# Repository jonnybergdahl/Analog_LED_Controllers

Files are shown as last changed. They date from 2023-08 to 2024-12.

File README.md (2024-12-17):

# Analog_LED_Controller

This repository contains 2 versions of a two channel analog LED controller. 

> Note: This is only suitable for LED lights powered by a fixed voltage, such as plant lights and LED strips. It does not work with raw LED's that need a constant current/voltage driver. 

One version is for 5V USB connected lights, the "USB version", and the other version is for 5-24V lights, the "Power jack version" using standard 5.5/2.1 mm power jacks. They are based on an ESP32-PICO-MINI-2 module, and I use it with ESPHome firmware to publish the lights to Home Assistant. Inside of Home Assistant you can dim the lights and turn them on or off. Both have a power jack input for power, make sure to use a power supply with center positive.

> Note: The boards have reverse power input protection for the internal circuitry only. The LED's outputs are protected by resettable fuses. This should not pose any problems as long as you only power LED's, since they are themselves diodes and thus already protected from reverse power.

The input power jack is rated for maximum 5A so depending on input voltage the max combined power is:
 - 5V: 25W
 - 12V: 60W
 - 24V: 120W

### USB version
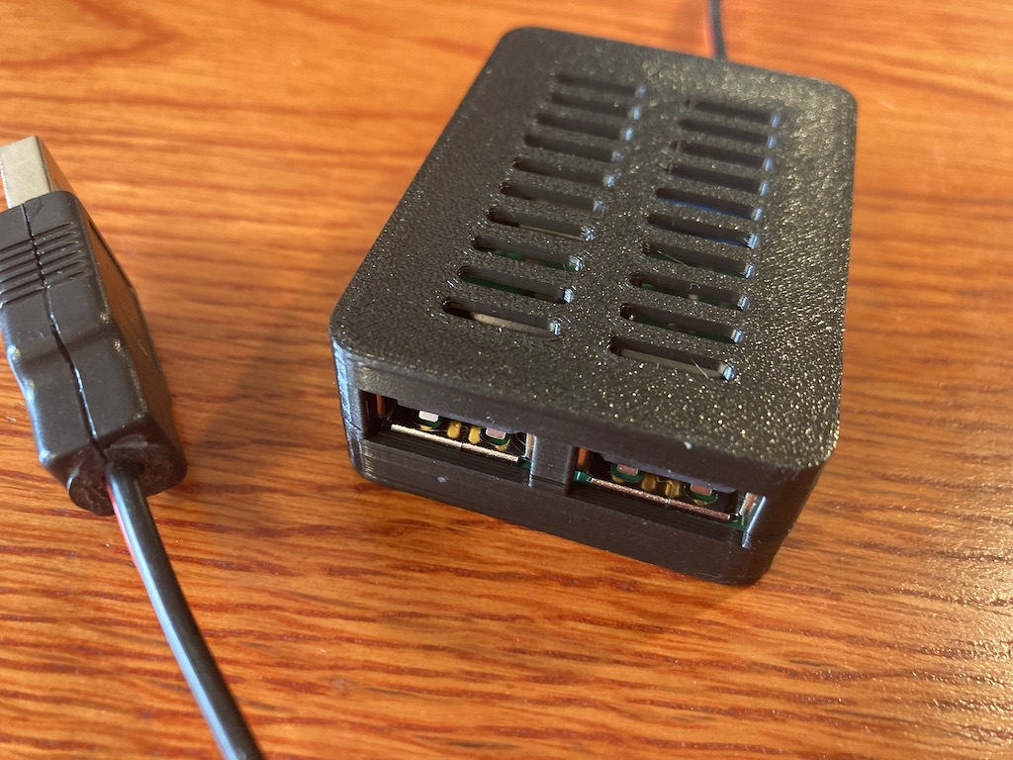
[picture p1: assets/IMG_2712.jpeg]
USB version


### Power jack version
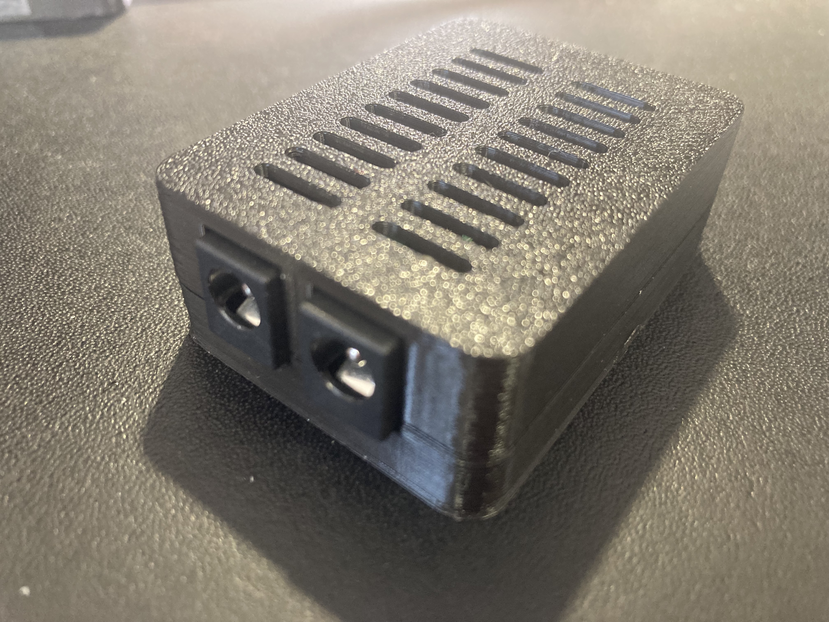
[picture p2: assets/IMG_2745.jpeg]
Power jack version


The gerber files for PCB manufacturing are located in the [gerber folder](gerber/).

I highly recommend you order a stencil together with the PCB, as the ESP32 module only exposes tiny pads on the bottom of the module and it is hard to get the correct amount of solder paste without one.

PCB design files are available in [EAGLE format](pcb/).

The Schematic is also available in PDF Format, [USB version](https://github.com/jonnybergdahl/Project_Analog_LED_Controllers/blob/main/pcb/5V_Analog_Controller.pdf) and [Power jack version](https://github.com/jonnybergdahl/Project_Analog_LED_Controllers/blob/main/pcb/12V_Analog_Controller.pdf).

## Parts needed

BOM file are located here: 
 - [USB version](pcb/USB_Analog_Controller.csv)
 - [Power jack version](pcb/USB_Analog_Controller%2024V.csv).

> Note: There is space for 2 PTC's per channel in case you need more current than a single PTC can handle. Make sure to use PTC's rated for the voltage _and_ current you want. The JK-SMD300L-24 in the BOM are rated for max 24V and a hold current of 3 ampere.

### USB version
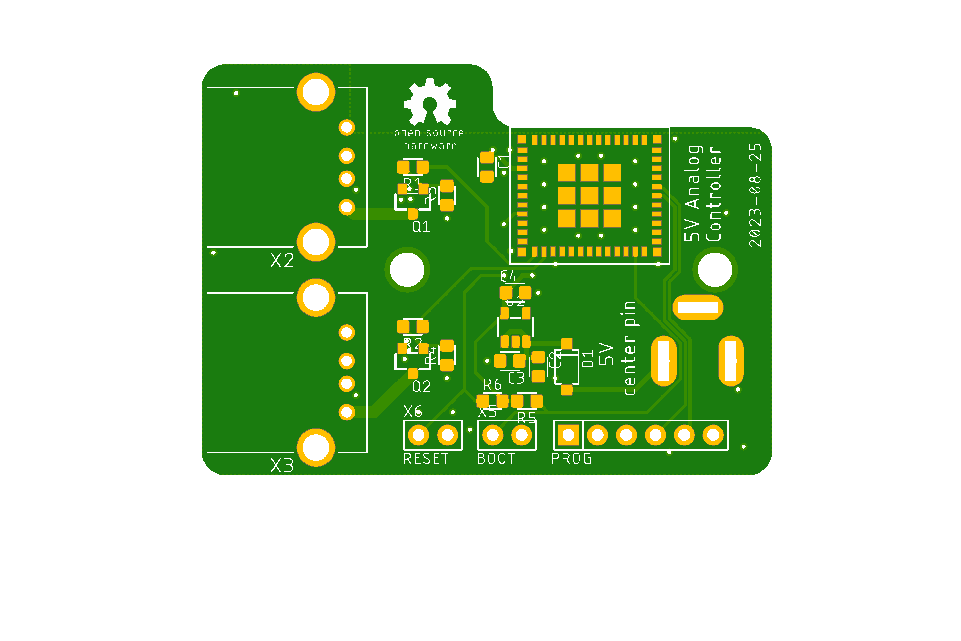
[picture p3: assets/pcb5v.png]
USB version PCB


### Power jack version
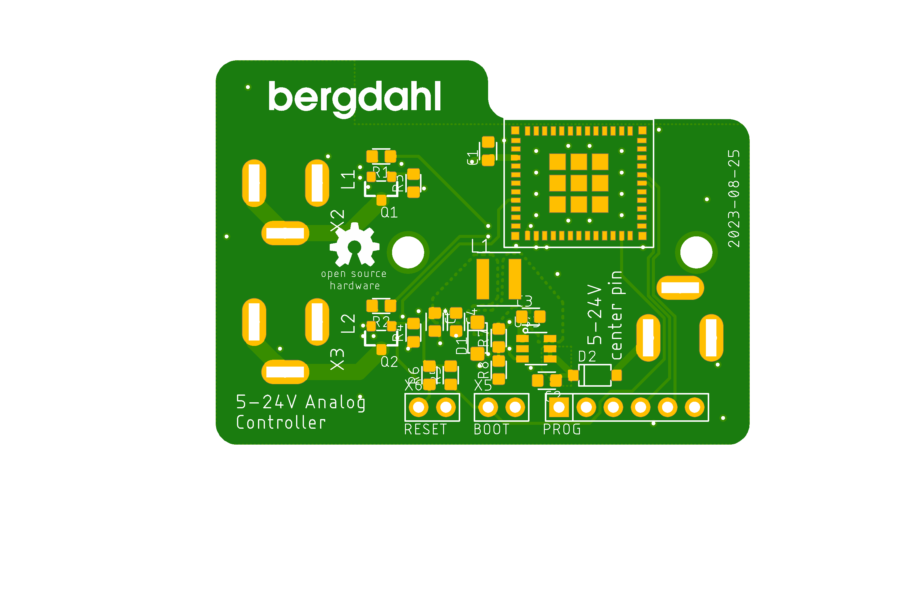
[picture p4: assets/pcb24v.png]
Power Jack version PCB


See the [BOM file](pcb/LED_USB_Analog_Controller.csv) for the component list.

## Enclosure

The enclosure files are located in the [enclosure folder](enclosure/). There are two `3mf` files for 3D printing for each device, and I also added the original _Fusion 360_ design files in case you need to make modifications.

## Assembly

 Start by soldering all SMD parts onto the PCB. I used a hot plate for resoldering, but a hot air soldering station will also work. Continue by using a soldering iron to solder the connectors. For the USB version, Cut an existing USB cable or do like me and solder up your own, and screw plus and minus to the screw terminals (Depending on the power usage of the lights, you may need thicker cables than normal USB cables, that is why I make my own power only ones). 

The enclosure is press fit so does not need any extra hardware or tools.

## Programming

Create a new device in _ESPHome_ and replace the `yaml` with the contents of [the yaml code here](firmware/led1.yaml). Change `name` and `friendly_name` as needed.

The actual programming is done by using a standard FT232 serial board connected to the programming header. If you don't own a FT232 adapter, you can use other types of serial adapters by hooking up `GND`, `TX` and `RX` like this.

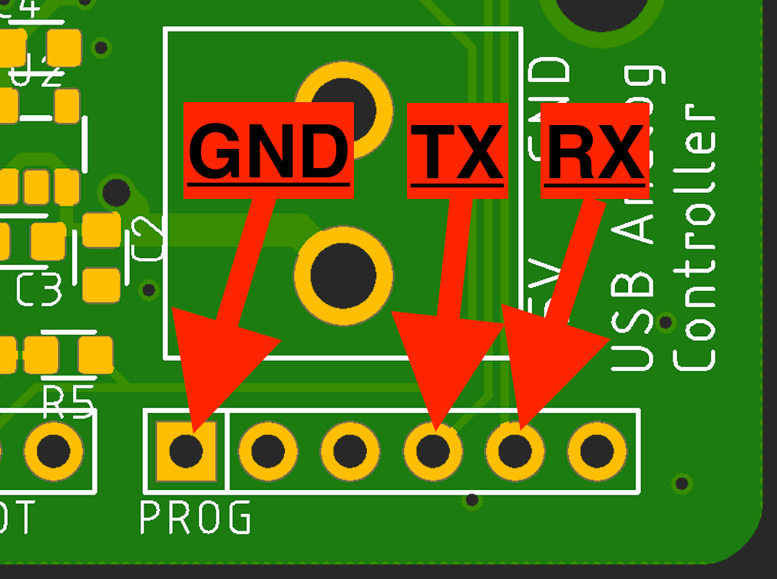
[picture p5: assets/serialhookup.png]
Serial connection


Insert the programmer and short the `BOOT` header. It can be done by soldering a temporary lead between the pads (I just insert tweezers into the pads). Apply power and it is ready for programming.

In _EspHome_,  click `Install` - `Manual download` - `Modern format`. _EspHome_ will compile the code and after couple of minutes the firmware file will be downloaded. 

Open the [ESPHome programming page](https://web.esphome.io/) and click `CONNECT`. Select the FT232 serial port and click `Connect`. Select `Install` and then click `Select file`. Select the file downloaded in the previous step and then click `Install`. The install will now proceed.

When install is finished, just remove the FT232 board and `BOOT` jumper, disconnect and connect power, and after a while Home Assistant will autodetect it. Just add the device as usual and you will get a device with the following entities in Home Assistant. 

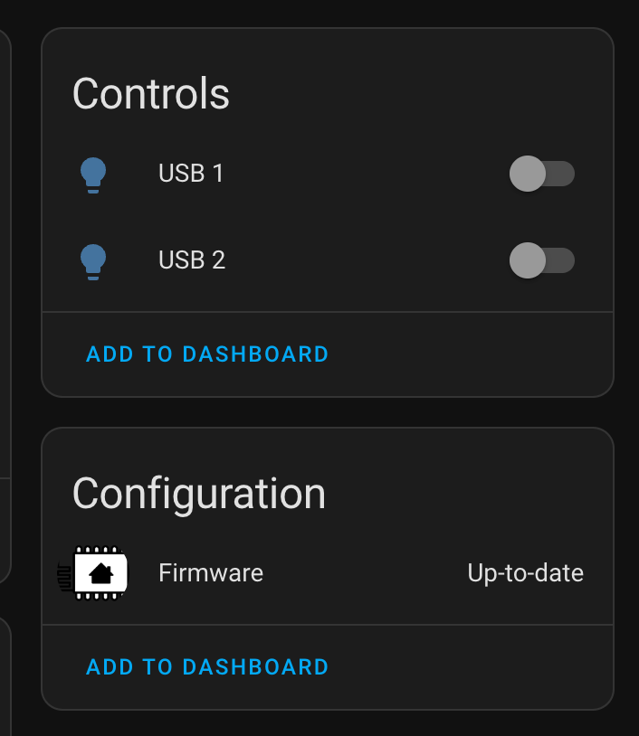
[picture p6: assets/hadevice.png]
Home Assistant view


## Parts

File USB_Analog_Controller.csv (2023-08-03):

Qty | Value | Device | Package | Parts | Description
2 | 100R | RESISTOR0603 | R0603 | R1, R2
1 | 100nF | CAPC0603 | C0603 | C1
4 | 10K | RESISTOR0603 | R0603 | R3, R4, R5, R6
3 | 1uF | CAPC0603 | C0603 | C2, C3, C4
2 | 3A | PTCJK-SMD300 | JK-SMD300 | F1, F2
2 | AO3400 | MOSFET-NCHSOT23-3 | SOT23-3 | Q1, Q2
1 | AP2112K | REGULATOR-AP2112KK-SOT23-5 | SOT23-5 | U2
1 | BOOT | HEADER-1X02-2.54 | 1X02-2.54 | X5
1 | LED1 | USB-ASS-52100-001 | USB-A-SS-52100-001 | X2
1 | LED2 | USB-ASS-52100-001 | USB-A-SS-52100-001 | X3
1 | PICO-MINI-02 | ESP32-PICO-MINI-02 | ESP32-PICO-MINI-02 | U1
1 | POWER | TERMINAL-1X02-5.08 | TERMINAL-5.08-2P | J1 | https://www.digikey.se/product-detail/sv/on-shore-technology-inc/OSTTC022162/ED2609-ND/614558
1 | PROG | HEADER-FTDI232 | FTDI232-1X06 | X1
1 | RESET | HEADER-1X02-2.54 | 1X02-2.54 | X6

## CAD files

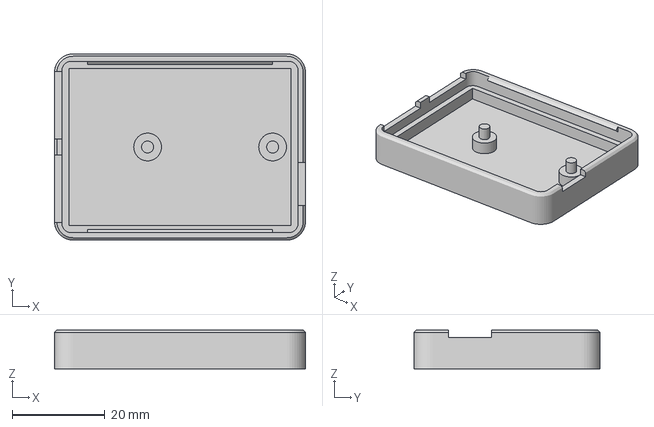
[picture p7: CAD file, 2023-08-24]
enclosure/5V Analog LED Controller Top.3mf
54.2 x 40.2 x 8.40 mm

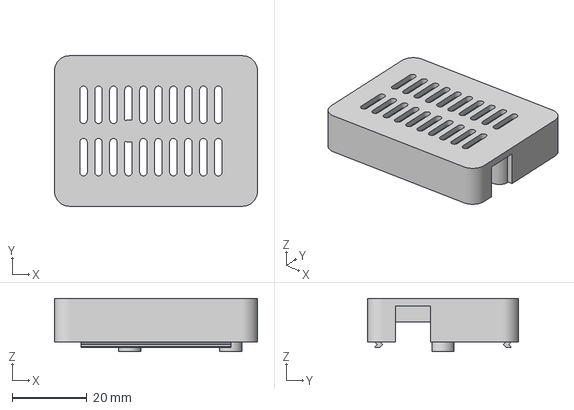
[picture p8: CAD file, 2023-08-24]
enclosure/5V Analog LED Controller Bottom.3mf
54.2 x 40.2 x 14.2 mm

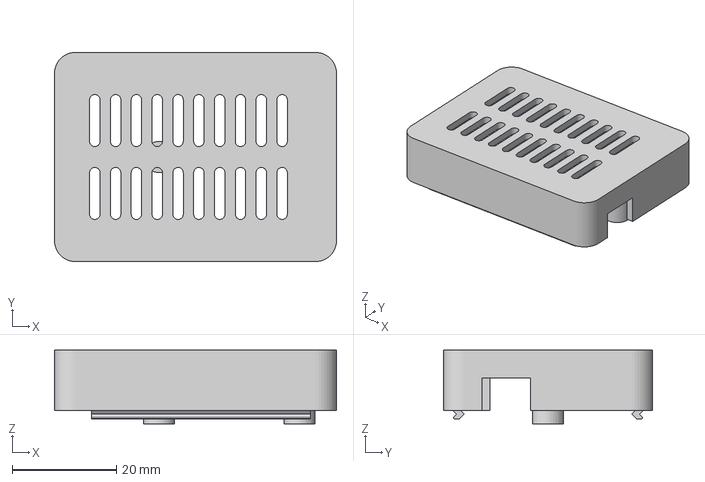
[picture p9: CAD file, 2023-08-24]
enclosure/12V Analog LED Controller Top.3mf
54.2 x 40.2 x 14.2 mm

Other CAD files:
enclosure/12V Analog LED Controller Bottom.3mf
enclosure/12V Analog LED Controller Enclosure.f3d
enclosure/5V Analog LED Controller Enclosure.f3d

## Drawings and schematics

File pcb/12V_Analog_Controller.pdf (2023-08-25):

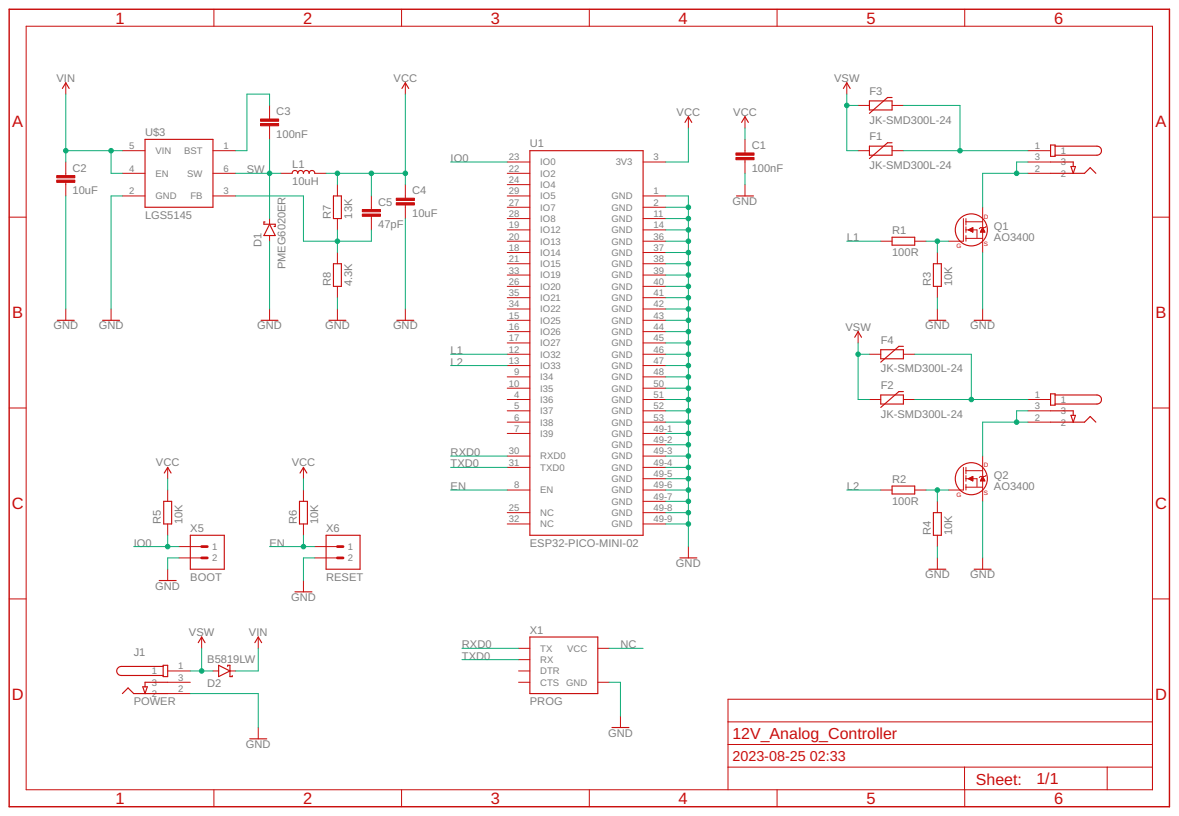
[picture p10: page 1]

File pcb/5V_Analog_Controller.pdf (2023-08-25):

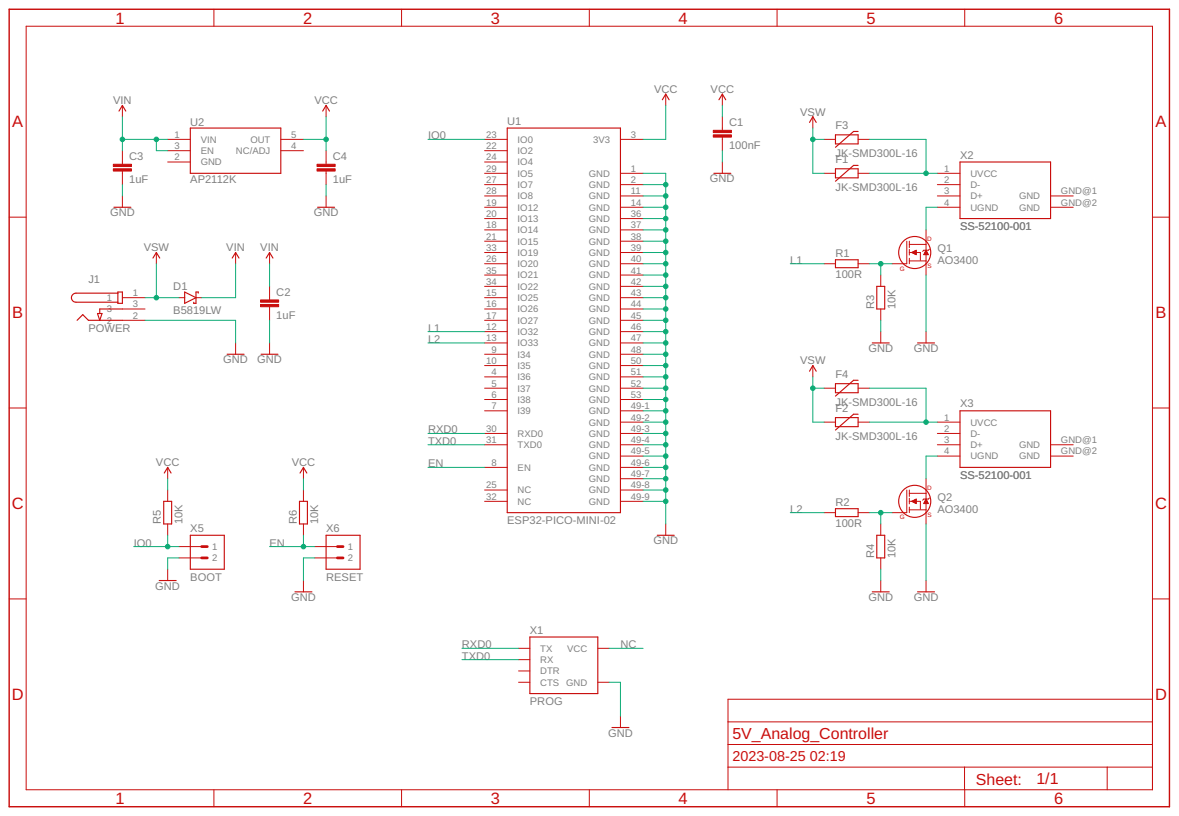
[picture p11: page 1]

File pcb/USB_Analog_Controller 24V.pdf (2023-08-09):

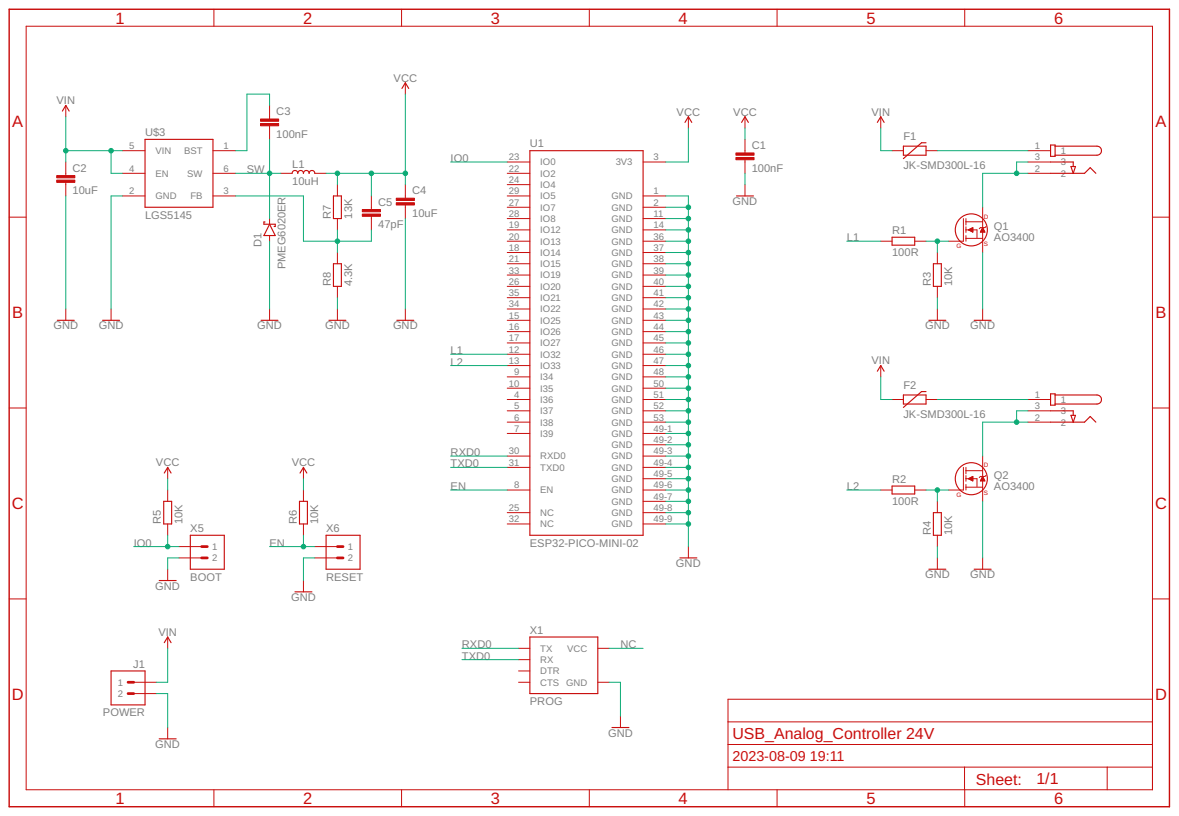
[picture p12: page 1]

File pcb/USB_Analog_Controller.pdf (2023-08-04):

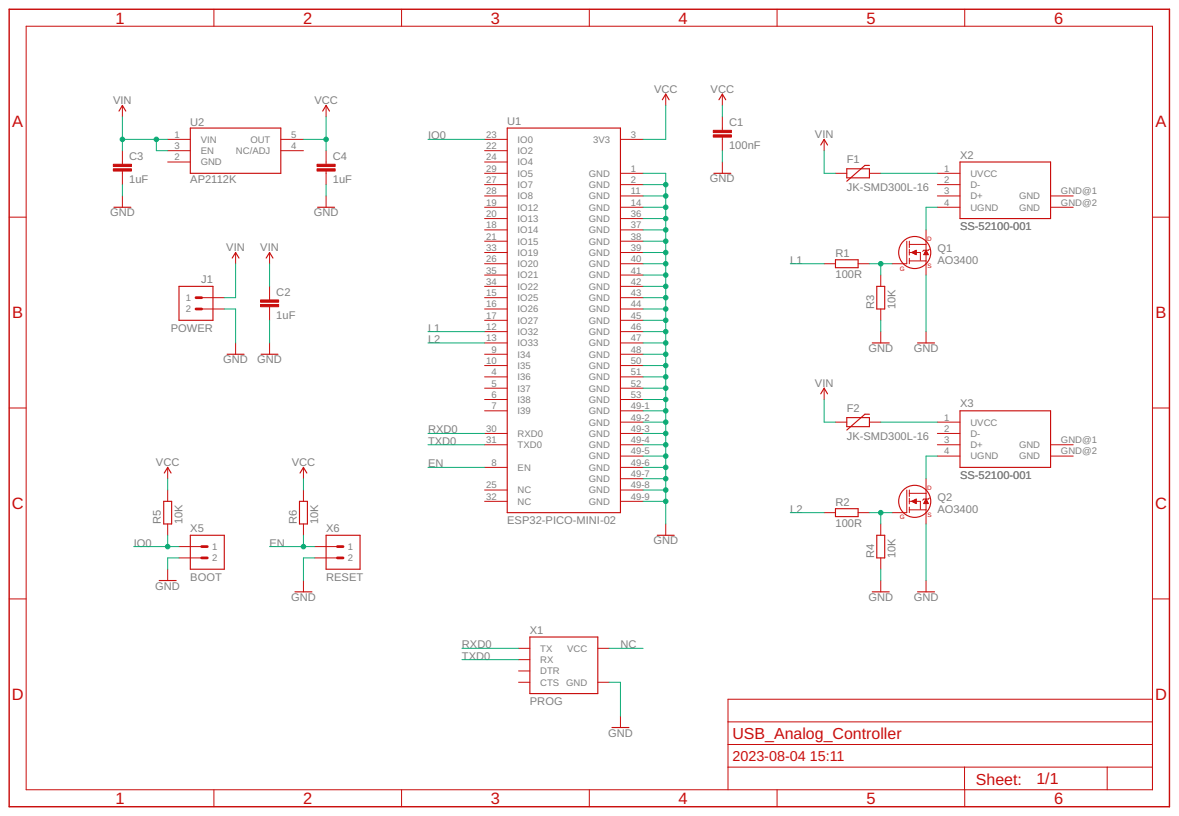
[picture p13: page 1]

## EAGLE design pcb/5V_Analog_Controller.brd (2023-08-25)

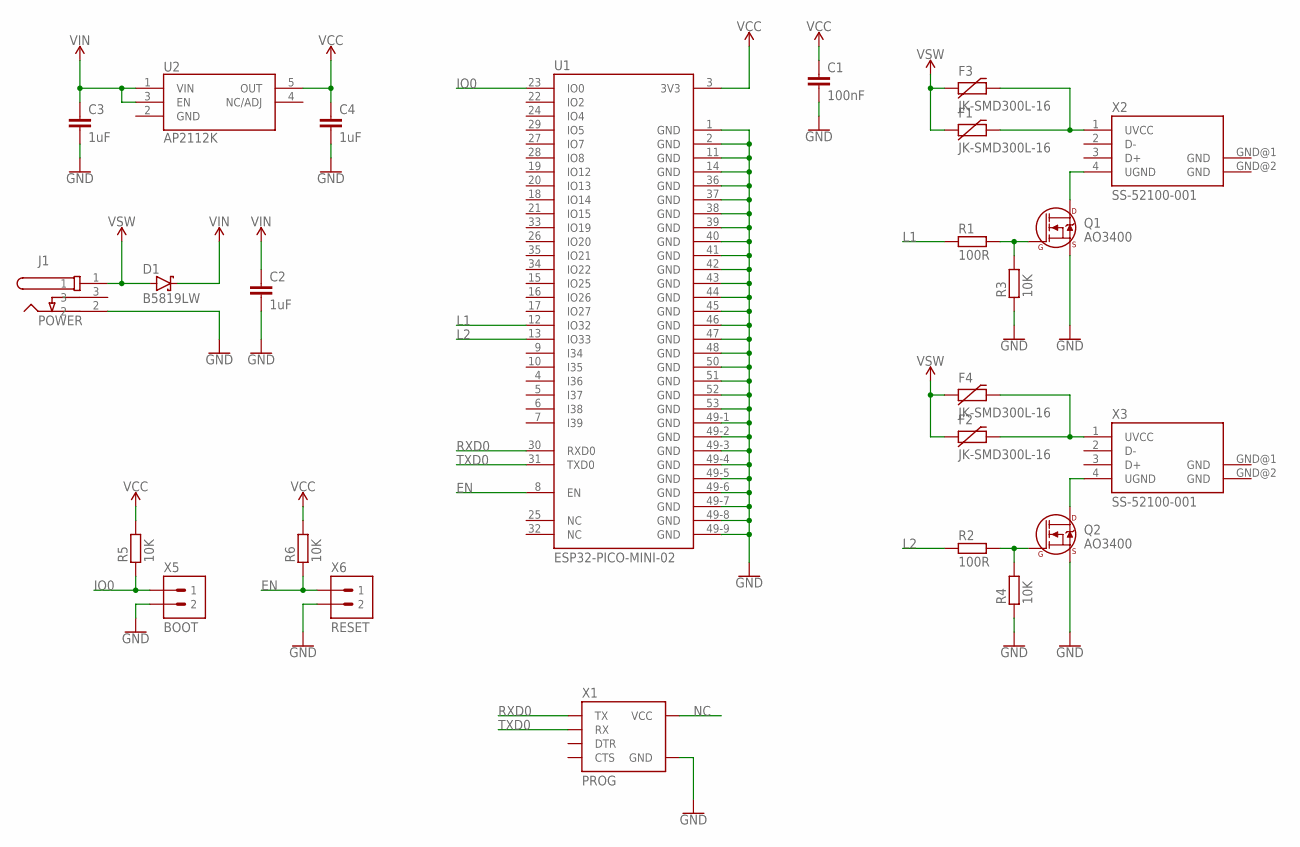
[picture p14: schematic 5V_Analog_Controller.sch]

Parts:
C1: 100nF; C0603
C2, C3, C4: 1uF; C0603
D1: B5819LW; SOD-123
F1, F2, F3, F4: JK-SMD300L-16; JK-SMD300
J1: POWER; XKB-DC-005-5A-2.0
Q1, Q2: AO3400; SOT23-3
R1, R2: 100R; R0603
R3, R4, R5, R6: 10K; R0603
U1: ESP32-PICO-MINI-02
U2: AP2112K; SOT23-5
X1: PROG; FTDI232-1X06
X2, X3: SS-52100-001; USB-A-SS-52100-001
X5: BOOT; 1X02-2.54
X6: RESET; 1X02-2.54

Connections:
EN: R6.1, U1.8 (EN), X6.1
GND: C1.2, C2.2, C3.2, C4.2, J1.2, Q1.2 (S), Q2.2 (S), R3.1, R4.1, U1.1 (GND), U1.2 (GND), U1.11 (GND), U1.14 (GND), U1.36 (GND), U1.37 (GND), U1.38 (GND), U1.39 (GND), U1.40 (GND), U1.41 (GND), U1.42 (GND), U1.43 (GND), U1.44 (GND), U1.45 (GND), U1.46 (GND), U1.47 (GND), U1.48 (GND), U1.49-1 (GND), U1.49-2 (GND), U1.49-3 (GND), U1.49-4 (GND), U1.49-5 (GND), U1.49-6 (GND), U1.49-7 (GND), U1.49-8 (GND), U1.49-9 (GND), U1.50 (GND), U1.51 (GND), U1.52 (GND), U1.53 (GND), U2.2 (GND), X1.GND, X5.2, X6.2
IO0: R5.1, U1.23 (IO0), X5.1
L1: R1.1, U1.12 (IO32)
L2: R2.1, U1.13 (IO33)
unnamed: Q1.3 (D), X2.4 (UGND)
unnamed: Q2.3 (D), X3.4 (UGND)
unnamed: Q2.1 (G), R2.2, R4.2
unnamed: Q1.1 (G), R1.2, R3.2
unnamed: F1.B (2), F3.B (2), X2.1 (UVCC)
unnamed: F2.B (2), F4.B (2), X3.1 (UVCC)
NC: X1.VCC
RXD0: U1.30 (RXD0), X1.TX
TXD0: U1.31 (TXD0), X1.RX
VCC: C1.1, C4.1, R5.2, R6.2, U1.3 (3V3), U2.5 (OUT)
VIN: C2.1, C3.1, D1.C, U2.1 (VIN), U2.3 (EN)
VSW: D1.A, F1.A (1), F2.A (1), F3.A (1), F4.A (1), J1.1

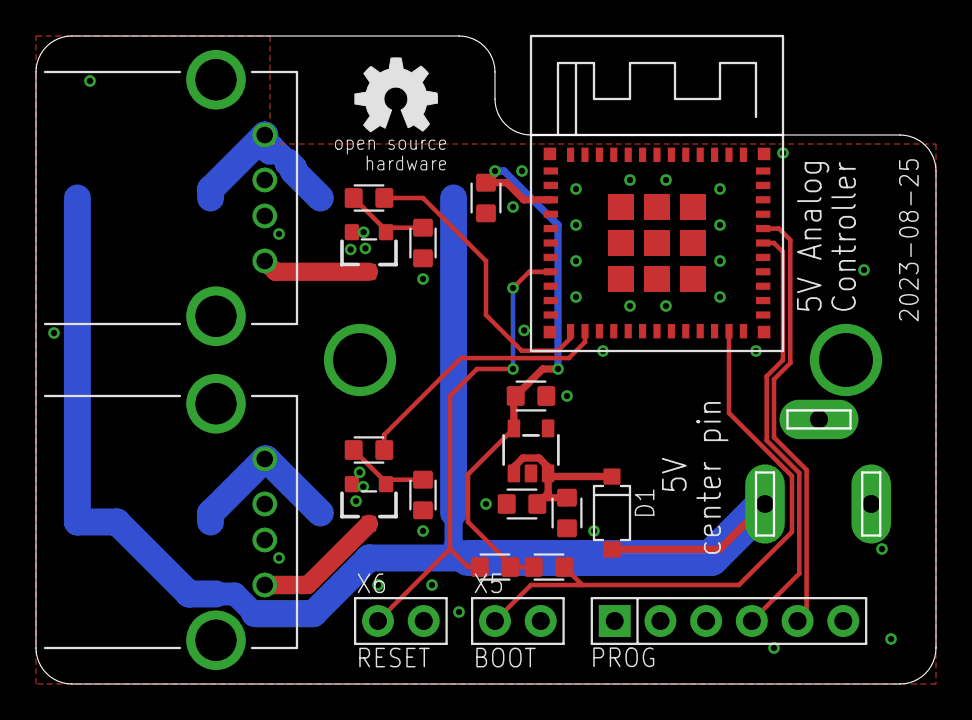
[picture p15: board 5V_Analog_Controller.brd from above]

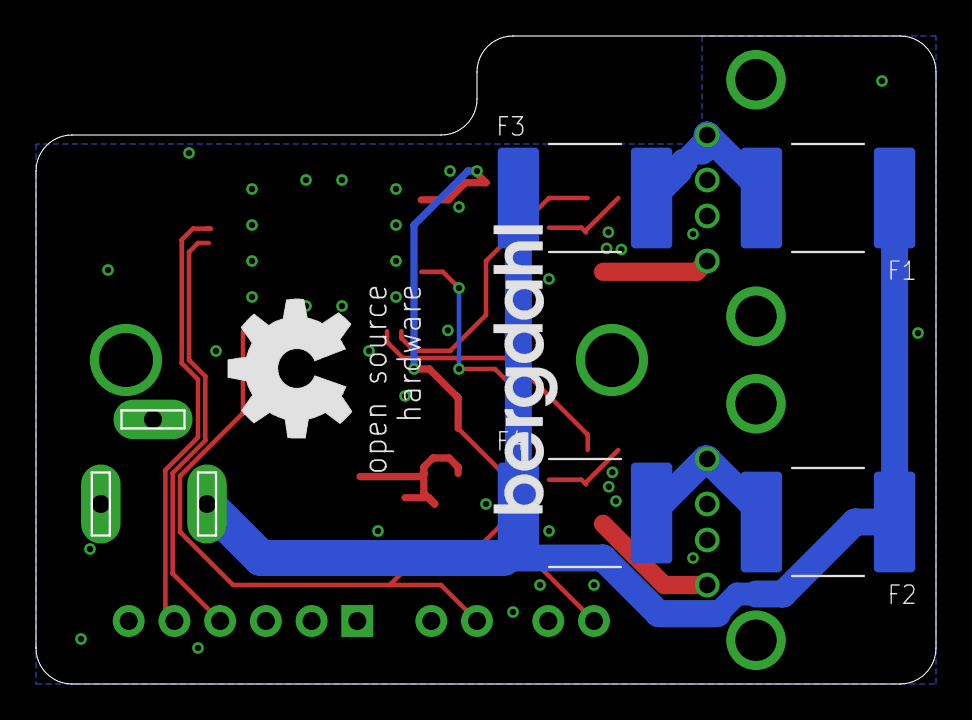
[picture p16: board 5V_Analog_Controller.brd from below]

Board: 2 copper layers, 50.0 x 36.0 mm, 28 parts (4 on the bottom side), 16 nets.

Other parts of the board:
U$1: BERGDAHL-20MM-BPLACE
U$2: OSHW-8MM-BPLACE
U$3: OSHW-5MM-TPLACE

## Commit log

2023-06-03 Initial version
    [LED_USB_Analog_Controller.brd, LED_USB_Analog_Controller.sch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]
2023-07-17 Revision 2023-07-17
    [LED_USB_Analog_Controller.csv, USB_Analog_Controller.brd, USB_Analog_Controller.sch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]
2023-07-27 Added PTC fuse
    [USB_Analog_Controller.brd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]
2023-08-03 Final PCB version
    [LED USB Analog Controller Enclosure.f3d, LED_USB_Analog_Controller.brd, LED_USB_Analog_Controller_Bottom.3mf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]
2023-08-04 Revision 2023-08-04 Switch power connector Add PDF file Cleanup old PCB files
    [LED_USB_Analog_Controller.brd, LED_USB_Analog_Controller.csv, LED_USB_Analog_Controller.sch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]
2023-08-09 Add 5-24V version
    [USB_Analog_Controller 24V.GBL, USB_Analog_Controller 24V.GBO, USB_Analog_Controller 24V.GBP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]
2023-08-09 Add missing drill file
2023-08-14 Change connector on24V PCB Cosmetic fixes on 24V PCB
    [USB_Analog_Controller 24V.brd, USB_Analog_Controller 24V.csv, USB_Analog_Controller 24V.sch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]
2023-08-20 Major renaming work
    [12V Analog LED Controller Bottom.3mf, 12V Analog LED Controller Enclosure.f3d, 12V Analog LED Controller Top.3mf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]
2023-08-20 Moved repo to better named location
    [12V_Analog_Controller.GBL, 12V_Analog_Controller.GBO, 12V_Analog_Controller.GBP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]
2023-08-20 Revert "Major renaming work"
    This reverts commit 9d1dc4bb5ff05094a4a5c98072b5adfe142c2125.
    [12V Analog LED Controller Bottom.3mf, 12V Analog LED Controller Enclosure.f3d, 12V Analog LED Controller Top.3mf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]
2023-08-20 Moved all files
    [12V Analog LED Controller Bottom.3mf, 12V Analog LED Controller Enclosure.f3d, 12V Analog LED Controller Top.3mf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]
2023-08-20 Fix snap issue
    [12V Analog LED Controller Bottom.3mf, 12V Analog LED Controller Enclosure.f3d, 12V Analog LED Controller Top.3mf]
2023-08-24 Switch to input power jack
    [12V_Analog_Controller.brd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]
2023-08-24 Add reverse power protection for internal circuits
    [12V_Analog_Controller.brd, 12V_Analog_Controller.sch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]
2023-08-24 Update enclosure files for power jack cutout
    [12V Analog LED Controller Bottom.3mf, 12V Analog LED Controller Enclosure.f3d, 12V Analog LED Controller Top.3mf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]
2023-08-25 Add second PTC footprint
    [12V_Analog_Controller.brd, 12V_Analog_Controller.sch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]
2023-08-25 Increased combined current capability
2023-08-25 Increase current capablity
    [12V_Analog_Controller.brd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]
